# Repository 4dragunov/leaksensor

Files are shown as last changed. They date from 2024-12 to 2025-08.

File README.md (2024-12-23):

# LoRaWAN end-device stack implementation and example projects

      ______                              _
     / _____)             _              | |
    ( (____  _____ ____ _| |_ _____  ____| |__
     \____ \| ___ |    (_   _) ___ |/ ___)  _ \
     _____) ) ____| | | || |_| ____( (___| | | |
    (______/|_____)_|_|_| \__)_____)\____)_| |_|
        (C)2013-2022 Semtech

     ___ _____ _   ___ _  _____ ___  ___  ___ ___
    / __|_   _/_\ / __| |/ / __/ _ \| _ \/ __| __|
    \__ \ | |/ _ \ (__| ' <| _| (_) |   / (__| _|
    |___/ |_/_/ \_\___|_|\_\_| \___/|_|_\\___|___|
    embedded.connectivity.solutions===============

## Introduction

The aim of this project is to show an example of an end-device LoRaWAN stack implementation.

This project has 2 active branches in place.

| Branch | L2 spec | RP spec | Tag/Milestone | Class | Comments |
| --- |:---:|:---:|:---:|:---:|:---|
| | [1.0.4](https://resources.lora-alliance.org/technical-specifications/ts001-1-0-4-lorawan-l2-1-0-4-specification) / [1.1.0](https://resources.lora-alliance.org/technical-specifications/lorawan-specification-v1-1) + [FCntDwn ERRATA](https://resources.lora-alliance.org/technical-specifications/fopts-encryption-usage-of-fcntdwn-errata-on-the-lorawan-l2-1-1-specification) | [2-1.0.3](https://resources.lora-alliance.org/technical-specifications/rp2-1-0-3-lorawan-regional-parameters) | [v4.7.0](https://github.com/Lora-net/LoRaMac-node/releases/tag/v4.7.0) | A/B/C | LoRaWAN L2 1.0.4 - **_Released_** |
| [master](https://github.com/Lora-net/LoRaMac-node/tree/master) | [1.0.4](https://resources.lora-alliance.org/technical-specifications/ts001-1-0-4-lorawan-l2-1-0-4-specification) / [1.1.0](https://resources.lora-alliance.org/technical-specifications/lorawan-specification-v1-1) + [FCntDwn ERRATA](https://resources.lora-alliance.org/technical-specifications/fopts-encryption-usage-of-fcntdwn-errata-on-the-lorawan-l2-1-1-specification) | [2-1.0.3](https://resources.lora-alliance.org/technical-specifications/rp2-1-0-3-lorawan-regional-parameters) | [v4.7.0](https://github.com/Lora-net/LoRaMac-node/milestone/10) | A/B/C |  LoRaWAN L2 1.0.4 / 1.1.0 |
| [v5.0.0-branch](https://github.com/Lora-net/LoRaMac-node/tree/v5.0.0-branch) | [1.0.4](https://resources.lora-alliance.org/technical-specifications/ts001-1-0-4-lorawan-l2-1-0-4-specification) / [1.1.0](https://resources.lora-alliance.org/technical-specifications/lorawan-specification-v1-1) + [FCntDwn ERRATA](https://resources.lora-alliance.org/technical-specifications/fopts-encryption-usage-of-fcntdwn-errata-on-the-lorawan-l2-1-1-specification) | [2-1.0.3](https://resources.lora-alliance.org/technical-specifications/rp2-1-0-3-lorawan-regional-parameters) | [M 5.0.0](https://github.com/Lora-net/LoRaMac-node/milestone/11) | A/B/C |  LoRaWAN L2 1.0.4 / 1.1.0 - Adds support for LR-FHSS modulation |

This project fully implements ClassA, ClassB and ClassC end-device classes and it also provides SX1272/73, SX1276/77/78/79, SX1261/2 and LR1110 radio drivers.

For each currently supported platform example applications are provided.

* **LoRaMac/fuota-test-01**: FUOTA test scenario 01 end-device example application. (Based on provided application common packages)

* **LoRaMac/periodic-uplink-lpp**: ClassA/B/C end-device example application. Periodically uplinks a frame using the Cayenne LPP protocol. (Based on provided application common packages)

* **ping-pong**: Point to point RF link example application.

* **rx-sensi**: Example application useful to measure the radio sensitivity level using an RF generator.

* **tx-cw**: Example application to show how to generate an RF Continuous Wave transmission.

**Note**: *Each LoRaWAN application example (LoRaMac/\*) includes an implementation of the LoRa-Alliance; LoRaWAN certification protocol.*

**Note**: *The LoRaWAN stack API documentation can be found at: http://stackforce.github.io/LoRaMac-doc/*

## Supported platforms

This project currently provides support for the below platforms.  
This project can be ported to other platforms using different MCU than the ones currently supported.  
The [Porting Guide](https://stackforce.github.io/LoRaMac-doc/LoRaMac-doc-v4.7.0/_p_o_r_t_i_n_g__g_u_i_d_e.html) document provides guide lines on how to port the project to other platforms.

* NAMote72
  * [NAMote72 platform documentation](doc/NAMote72-platform.md)

* NucleoLxxx - Discovery kit
  * [NucleoLxxx and Discovery kit platforms documentation](doc/NucleoLxxx-platform.md)

* SKiM880B, SKiM980A, SKiM881AXL
  * [SKiM88xx platforms documentation](doc/SKiM88xx-platform.md)

* SAMR34
  * [SAMR34 platform documentation](doc/SAMR34-platform.md)

## Getting Started

### Prerequisites

Please follow instructions provided by [Development environment](doc/development-environment.md) document.

### Cloning the repository

Clone the repository from GitHub

```bash
$ git clone https://github.com/lora-net/loramac-node.git loramac-node
```

LoRaMac-node project contains Git submodules that must be initialized

```bash
$ cd loramac-node
$ git submodule update --init
```

### Secure-element commissioning

This project currently supports 3 different secure-elements `soft-se`, `lr1110-se`
and `atecc608a-tnglora-se` implementations.

In order to personalize the MCU binary file with LoRaWAN EUIs or/and AES128 keys
one must follow the instructions provided by [soft-se](####soft-se),
 [lr1110-se](####lr1110-se) and [atecc608a-tnglora-se](####atecc608a-tnglora-se) chapters

#### soft-se

*soft-se* is a pure software emulation of a secure-element. It means that everything is located on the host MCU memories. The `DevEUI`, `JoinEUI` and `AES128 keys` may be stored on a non-volatile memory through dedicated APIs.

In order to update the end-device identity (`DevEUI`, `JoinEUI` and `AES128 keys`) one must update the `se-identity.h` file located under `./src/peripherals/soft-se/` directory.  

**Note:** In previous versions of this project this was done inside `Commissioning.h` files located under each provided example directory.

#### lr1110-se

*lr1110-se* abstraction implementation handles all the required exchanges with the LR1110 radio crypto-engine.

All LR1110 radio chips are pre-provisioned out of factory in order to be used with [LoRa Cloud Device Join Service](https://www.loracloud.com/documentation/join_service).  

In case other Join Servers are to be used the `DevEUI`, `Pin`, `JoinEUI` and `AES128 keys` can be updated by following the instructions provided on chapter "13. LR1110 Provisioning" of the [LR1110 User Manual](https://semtech.my.salesforce.com/sfc/p/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).

When the compile option `SECURE_ELEMENT_PRE_PROVISIONED` is set to `ON` the *lr1110-se* will use the factory provisioned data (`DevEUI`, `JoinEUI` and `AES128 keys`).  
When the compile option `SECURE_ELEMENT_PRE_PROVISIONED` is set to `OFF` the *lr1110-se* has to be provisioned by following one of the methods described on chapter "13. LR1110 Provisioning" of the [LR1110 User Manual](https://semtech.my.salesforce.com/sfc/p/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).
The `DevEUI`, `Pin` and `JoinEUI` can be changed by editing the `se-identity.h` file located in `./src/peripherals/lr1110-se/` directory.

#### atecc608a-tnglora-se

The *atecc608a-tnglora-se* abstraction implementation handles all the required exchanges with the ATECC608A-TNGLORA and ATECC608B-TNGLORA secure-elements.

This secure-element is always pre-provisioned and its contents can't be changed.

### Building Process

#### Command line

**periodic-uplink-lpp** example for NucleoL476 platform with LR1110MB1DIS MBED shield and using LR1110 pre-provisioned secure-element

```bash
$ mkdir build
$ cd build
$ cmake -DCMAKE_BUILD_TYPE=Release \
        -DTOOLCHAIN_PREFIX="<replace by toolchain path>" \
        -DCMAKE_TOOLCHAIN_FILE="../cmake/toolchain-arm-none-eabi.cmake" \
        -DAPPLICATION="LoRaMac" \
        -DSUB_PROJECT="periodic-uplink-lpp" \
        -DCLASSB_ENABLED="ON" \
        -DACTIVE_REGION="LORAMAC_REGION_EU868" \
        -DREGION_EU868="ON" \
        -DREGION_US915="OFF" \
        -DREGION_CN779="OFF" \
        -DREGION_EU433="OFF" \
        -DREGION_AU915="OFF" \
        -DREGION_AS923="OFF" \
        -DREGION_CN470="OFF" \
        -DREGION_KR920="OFF" \
        -DREGION_IN865="OFF" \
        -DREGION_RU864="OFF" \
        -DBOARD="NucleoL476" \
        -DMBED_RADIO_SHIELD="LR1110MB1XXS" \
        -DSECURE_ELEMENT="LR1110_SE" \
        -DSECURE_ELEMENT_PRE_PROVISIONED="ON" \
        -DUSE_RADIO_DEBUG="ON" ..
$ make
```

**ping-pong** example using LoRa modulation for NucleoL476 platform with LR1110MB1DIS MBED shield

```bash
$ mkdir build
$ cd build
$ cmake -DCMAKE_BUILD_TYPE=Release \
        -DTOOLCHAIN_PREFIX="<replace by toolchain path>" \
        -DCMAKE_TOOLCHAIN_FILE="../cmake/toolchain-arm-none-eabi.cmake" \
        -DAPPLICATION="ping-pong" \
        -DMODULATION:"LORA" \
        -DREGION_EU868="ON" \
        -DREGION_US915="OFF" \
        -DREGION_CN779="OFF" \
        -DREGION_EU433="OFF" \
        -DREGION_AU915="OFF" \
        -DREGION_AS923="OFF" \
        -DREGION_CN470="OFF" \
        -DREGION_KR920="OFF" \
        -DREGION_IN865="OFF" \
        -DREGION_RU864="OFF" \
        -DBOARD="NucleoL476" \
        -DMBED_RADIO_SHIELD="LR1110MB1XXS" \
        -DUSE_RADIO_DEBUG="ON" ..
$ make
```

#### VSCode

**periodic-uplink-lpp** example for NucleoL476 platform with LR1110MB1DIS MBED shield and using LR1110 pre-provisioned secure-element

* Please edit .vscode/settings.json file

<details>
  <summary>Click to expand!</summary>
<p>

```json
// Place your settings in this file to overwrite default and user settings.
{
    "cmake.configureSettings": {

        // In case your GNU ARM-Toolchain is not installed under the default
        // path:
        //     Windows : No default path. Specify the path where the
        //               toolchain is installed. i.e:
        //               "C:/PROGRA~2/GNUTOO~1/92019-~1".
        //     Linux   : /usr
        //     OSX     : /usr/local
        // It is required to uncomment and to fill the following line.
        "TOOLCHAIN_PREFIX":"/path/to/toolchain",

        // In case your OpenOCD is not installed under the default path:
        //     Windows : C:/openocd/bin/openocd.exe
        //     Linux   : /usr/bin/openocd
        //     OSX     : /usr/local/bin/openocd
        // Please uncomment the following line and fill it accordingly.
        //"OPENOCD_BIN":"C:/openocd/bin/openocd.exe",

        // Specifies the path to the CMAKE toolchain file.
        "CMAKE_TOOLCHAIN_FILE":"cmake/toolchain-arm-none-eabi.cmake",

        // Determines the application. You can choose between:
        // LoRaMac (Default), ping-pong, rx-sensi, tx-cw.
        "APPLICATION":"LoRaMac",

        // Select LoRaMac sub project. You can choose between:
        // periodic-uplink-lpp, fuota-test-01.
        "SUB_PROJECT":"periodic-uplink-lpp",

        // Switch for Class B support of LoRaMac:
        "CLASSB_ENABLED":"ON",

        // Select the active region for which the stack will be initialized.
        // You can choose between:
        // LORAMAC_REGION_EU868, LORAMAC_REGION_US915, ..
        "ACTIVE_REGION":"LORAMAC_REGION_EU868",

        // Select the type of modulation, applicable to the ping-pong or
        // rx-sensi applications. You can choose between:
        // LORA or FSK
        "MODULATION":"LORA",

        // Target board, the following boards are supported:
        // NAMote72, NucleoL073 (Default), NucleoL152, NucleoL476, SAMR34, SKiM880B, SKiM980A, SKiM881AXL, B-L072Z-LRWAN1.
        "BOARD":"NucleoL476",

        // MBED Radio shield selection. (Applies only to Nucleo platforms)
        // The following shields are supported:
        // SX1272MB2DAS, SX1276MB1LAS, SX1276MB1MAS, SX1261MBXBAS(Default), SX1262MBXCAS, SX1262MBXDAS, LR1110MB1XXS.
        "MBED_RADIO_SHIELD":"LR1110MB1XXS",

        // Secure element type selection the following are supported
        // SOFT_SE(Default), LR1110_SE, ATECC608A_TNGLORA_SE
        "SECURE_ELEMENT":"LR1110_SE",

        // Secure element is pre-provisioned
        "SECURE_ELEMENT_PRE_PROVISIONED":"ON",

        // Region support activation, Select the ones you want to support.
        // By default only REGION_EU868 support is enabled.
        "REGION_EU868":"ON",
        "REGION_US915":"OFF",
        "REGION_CN779":"OFF",
        "REGION_EU433":"OFF",
        "REGION_AU915":"OFF",
        "REGION_AS923":"OFF",
        "REGION_CN470":"OFF",
        "REGION_KR920":"OFF",
        "REGION_IN865":"OFF",
        "REGION_RU864":"OFF",
        "USE_RADIO_DEBUG":"ON"
    }
}
```

</p>
</details>

* Click on "CMake: Debug: Ready" and select build type Debug or Release.  
cmake configure
* Wait for configuration process to finish
* Click on "Build" to build the project.  
cmake build
* Wait for build process to finish
* Binary files will be available under `./build/src/apps/LoRaMac/`
  * LoRaMac-periodic-uplink-lpp     - elf format
  * LoRaMac-periodic-uplink-lpp.bin - binary format
  * LoRaMac-periodic-uplink-lpp.hex - hex format

**ping-pong** example using LoRa modulation for NucleoL476 platform with LR1110MB1DIS MBED shield

* Please edit .vscode/settings.json file

<details>
  <summary>Click to expand!</summary>
<p>

```json
// Place your settings in this file to overwrite default and user settings.
{
    "cmake.configureSettings": {

        // In case your GNU ARM-Toolchain is not installed under the default
        // path:
        //     Windows : No default path. Specify the path where the
        //               toolchain is installed. i.e:
        //               "C:/PROGRA~2/GNUTOO~1/92019-~1".
        //     Linux   : /usr
        //     OSX     : /usr/local
        // It is required to uncomment and to fill the following line.
        "TOOLCHAIN_PREFIX":"/path/to/toolchain",

        // In case your OpenOCD is not installed under the default path:
        //     Windows : C:/openocd/bin/openocd.exe
        //     Linux   : /usr/bin/openocd
        //     OSX     : /usr/local/bin/openocd
        // Please uncomment the following line and fill it accordingly.
        //"OPENOCD_BIN":"C:/openocd/bin/openocd.exe",

        // Specifies the path to the CMAKE toolchain file.
        "CMAKE_TOOLCHAIN_FILE":"cmake/toolchain-arm-none-eabi.cmake",

        // Determines the application. You can choose between:
        // LoRaMac (Default), ping-pong, rx-sensi, tx-cw.
        "APPLICATION":"ping-pong",

        // Select LoRaMac sub project. You can choose between:
        // periodic-uplink-lpp, fuota-test-01.
        "SUB_PROJECT":"periodic-uplink-lpp",

        // Switch for Class B support of LoRaMac:
        "CLASSB_ENABLED":"ON",

        // Select the active region for which the stack will be initialized.
        // You can choose between:
        // LORAMAC_REGION_EU868, LORAMAC_REGION_US915, ..
        "ACTIVE_REGION":"LORAMAC_REGION_EU868",

        // Select the type of modulation, applicable to the ping-pong or
        // rx-sensi applications. You can choose between:
        // LORA or FSK
        "MODULATION":"LORA",

        // Target board, the following boards are supported:
        // NAMote72, NucleoL073 (Default), NucleoL152, NucleoL476, SAMR34, SKiM880B, SKiM980A, SKiM881AXL, B-L072Z-LRWAN1.
        "BOARD":"NucleoL476",

        // MBED Radio shield selection. (Applies only to Nucleo platforms)
        // The following shields are supported:
        // SX1272MB2DAS, SX1276MB1LAS, SX1276MB1MAS, SX1261MBXBAS(Default), SX1262MBXCAS, SX1262MBXDAS, LR1110MB1XXS.
        "MBED_RADIO_SHIELD":"SX1261MBXBAS",

        // Secure element type selection the following are supported
        // SOFT_SE(Default), LR1110_SE, ATECC608A_TNGLORA_SE
        "SECURE_ELEMENT":"SOFT_SE",

        // Secure element is pre-provisioned
        "SECURE_ELEMENT_PRE_PROVISIONED":"ON",

        // Region support activation, Select the ones you want to support.
        // By default only REGION_EU868 support is enabled.
        "REGION_EU868":"ON",
        "REGION_US915":"OFF",
        "REGION_CN779":"OFF",
        "REGION_EU433":"OFF",
        "REGION_AU915":"OFF",
        "REGION_AS923":"OFF",
        "REGION_CN470":"OFF",
        "REGION_KR920":"OFF",
        "REGION_IN865":"OFF",
        "REGION_RU864":"OFF",
        "USE_RADIO_DEBUG":"ON"
    }
}
```

</p>
</details>

* Click on "CMake: Debug: Ready" and select build type Debug or Release.  
cmake configure
* Wait for configuration process to finish
* Click on "Build" to build the project.  
cmake build
* Wait for build process to finish
* Binary files will be available under `./build/src/apps/ping-pong/`
  * ping-pong     - elf format
  * ping-pong.bin - binary format
  * ping-pong.hex - hex format

### Serial console NVM management

The `periodic-uplink-lpp` and `fuota-test-01` examples allow to reset the NVM storage through the serial interface.

In order to reset the NVM contents one must hit `ESC` + `N` keyboard keys on a serial terminal.

The serial terminal will show the following after `ESC` + `N` keyboard keys are hit. After reseting the end-device the clean NVM will be used.

```text
ESC + N

NVM factory reset succeed

PLEASE RESET THE END-DEVICE
```

## Acknowledgments

* The mbed (https://mbed.org/) project was used at the beginning as source of
inspiration.
* This program uses the AES algorithm implementation (http://www.gladman.me.uk/) by Brian Gladman.
* This program uses the CMAC algorithm implementation
(http://www.cse.chalmers.se/research/group/dcs/masters/contikisec/) by Lander Casado, Philippas Tsigas.
* [The Things Industries](https://www.thethingsindustries.com/) for providing
 Microchip/Atmel SAMR34 platform and ATECC608A-TNGLORA secure-element support.
* Tencent Blade Team for security breach findings and solving propositions.

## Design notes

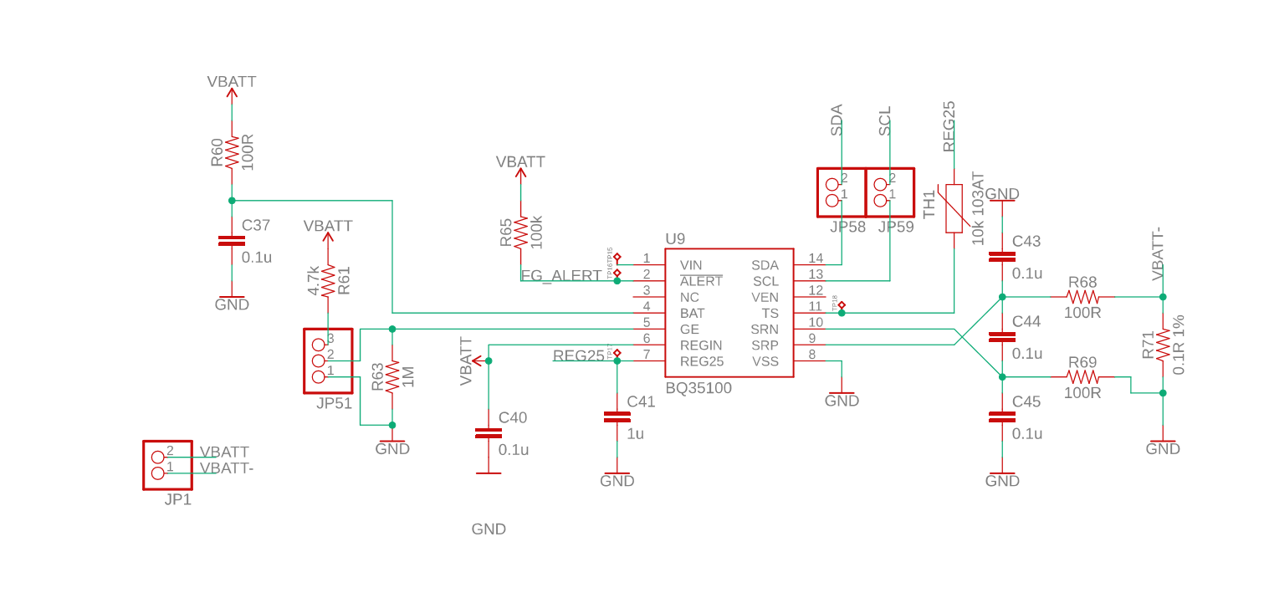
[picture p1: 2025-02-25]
doc/board/water-leak/3362.schematic.png

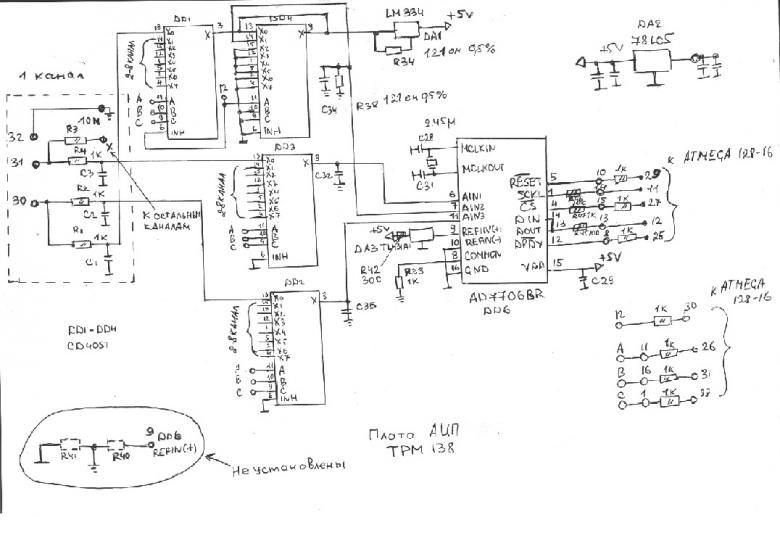
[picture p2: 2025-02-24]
doc/board/trm138_dac_-_kopiya.jpg

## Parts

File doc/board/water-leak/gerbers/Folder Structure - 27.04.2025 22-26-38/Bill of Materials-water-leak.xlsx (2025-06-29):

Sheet: Sheet1
 | Bill of Materials
 |  |  |  |  |  |  | 2175 Salk Avenue
 | Project Title: | Bill of Materials for Project [water-leak.PrjPcb] (No PCB Document Selected) |  |  |  |  | Suite 200
 | Project File Name: | water-leak.PrjPcb |  |  |  |  | Carlsbad, CA 92008
 | Assembly Variant: | None |  |  |  |  | USA
Part Number | Description | Designator | Manufacture | Manufacture Part Number | Supplier | Supplier Part Number | Supplier Unit Price | Quantity
AMAN903012ST05 | RF Ant 434/868/915MHz | A1 |  |  |  |  |  | 1
ML-621SDN | No Description Available | B1 |  |  |  |  |  | 1
TMK107BBJ475KA-T | SMT Capacitor | C1, C7, C11 |  |  | DigiKey | 587-4321-1-ND |  | 3
CL10B104KO8NNNC, VJ0603Y104MXQCW1BC | SMT Capacitor | C2, C3, C4, C5, C6, C8, C12, C13, C38_SI0, C38_SI1, C39_SI0, C39_SI1, C40_SI0, C40_SI1, C41_SI0, C41_SI1, C42_SI0, C42_SI1, C52, C53, C54, C55, C58, C81 |  |  | DigiKey | 1276-1005-1-ND, 720-VJ0603Y104MXQCW1BCCT-ND |  | 24
QSCP251Q5R1C1GV001T | SMT Capacitor | C9, C10, C23 |  |  | DigiKey | 712-QSCP251Q5R1C1GV001TCT-ND |  | 3
EEE-FK1V471SP | Capacitor Polarised | C14 |  |  |  |  |  | 1
VJ0603D100JXPAJ, VJ0603D100FXPAJ | SMT Capacitor | C15, C27, C80 |  |  | DigiKey | 720-1299-1-ND, 720-VJ0603D100FXPAJCT-ND |  | 3
C0603X152J4HAC7867 | SMT Capacitor | C16_SI0, C16_SI1, C26, C31, C35, C62, C63, C64, C65 |  |  | DigiKey | 399-C0603X152J4HAC7867CT-ND |  | 9
VJ0603Y102JXACW1BC | SMT Capacitor | C17, C28 |  |  | DigiKey | 720-VJ0603Y102JXACW1BCCT-ND |  | 2
UMK107B7474KA-TR | SMT Capacitor | C18 |  |  | DigiKey | 587-3170-1-ND |  | 1
VJ0603Y473KXJCW1BC | SMT Capacitor | C19 |  |  | DigiKey | 720-VJ0603Y473KXJCW1BCCT-ND |  | 1
VJ0603D680JXAQJHT, VJ0603D680JXCAJ | SMT Capacitor | C20, C22 |  |  | DigiKey | 720-VJ0603D680JXAQJHTCT-ND, 720-VJ0603D680JXCAJCT-ND |  | 2
VJ0603D2R0BXPAJ | SMT Capacitor | C21 |  |  | DigiKey | 720-1310-1-ND |  | 1
VJ0603D0R7VXPAJ | SMT Capacitor | C24 |  |  | DigiKey | 720-VJ0603D0R7VXPAJCT-ND |  | 1
VJ0603D0R7VXPAJ | SMT Capacitor | C25 |  |  | DigiKey | 720-VJ0603D0R7VXPAJCT-ND |  | 1
VJ0603D3R0BXPAJ | SMT Capacitor | C29 |  |  | DigiKey | 720-1317-1-ND |  | 1
C4532X5R0J107M280KA | SMT Capacitor | C30, C69, C70 |  |  | DigiKey | 445-1413-1-ND |  | 3
VJ0603D1R0BXCQJHT | SMT Capacitor | C32 |  |  | DigiKey | 720-VJ0603D1R0BXCQJHTCT-ND |  | 1
VJ0603D3R3CXBAJ | SMT Capacitor | C33, C34 |  |  | DigiKey | 720-VJ0603D3R3CXBAJCT-ND |  | 2
VJ0603D4R7CXPAJ | SMT Capacitor | C36 |  |  | DigiKey | 720-1321-1-ND |  | 1
VJ0603D330FXPAJ | SMT Capacitor | C37, C57, C79 |  |  | DigiKey | 720-VJ0603D330FXPAJCT-ND |  | 3
VJ0603Y105KXJPW1BC, VJ0603Y105KXJCW1BC | SMT Capacitor | C47, C48, C50, C56 |  |  | DigiKey | 720-VJ0603Y105KXJPW1BCCT-ND, 720-1852-1-ND |  | 4
VJ0603Y332KXAAC | SMT Capacitor | C49 |  |  | DigiKey | 720-1366-1-ND |  | 1
6SVPE150M | SMT Polarised Capacitor | C51 |  |  | DigiKey | P16614CT-ND |  | 1
VJ0603D220JXBQJHT | SMT Capacitor | C59 |  |  | DigiKey | 720-VJ0603D220JXBQJHTCT-ND |  | 1
ZRB186R60J226ME11L | SMT Capacitor | C60, C61, C66, C67 |  |  | DigiKey | 490-13254-1-ND |  | 4
1210DD105KAT2A | SMT Capacitor | C71 |  |  | DigiKey | 478-12269-1-ND |  | 1
GCM1885C2A5R0CA16D | DNP, SMT Capacitor | C82, C83 |  |  | DigiKey | 490-GCM1885C2A5R0CA16DCT-ND |  | 2
CC0805MRX7R9BB104 | SMT Capacitor | C84, C86 |  |  | DigiKey | 311-4351-1-ND |  | 2
VJ0805G106KXYTW1BC | SMT Capacitor | C85 |  |  | DigiKey | 720-VJ0805G106KXYTW1BCCT-ND |  | 1
VJ0805G106KXYTW1BC | SMT Capacitor | C87 |  |  | DigiKey | 720-VJ0805G106KXYTW1BCCT-ND |  | 1
PESD3V3L2BT | TVS Diode (Uni-directional) | D3_WS1, D3_WS2, D3_WS3, D3_WS4, D3_WS5, D3_WS6, D3_WS7, D3_WS8, D3_WS9, D3_WS10, D3_WS11, D3_WS12, D3_WS13, D3_WS14, D3_WS15, D3_WS16, D3_WS17, D3_WS18, D3_WS19, D3_WS20 |  |  |  |  |  | 20
10MQ040NTR | DIODE SCHOTTKY 40V 1A SMA | D4 |  |  | DigiKey | 1655-2293-1-ND |  | 1
1KSMB33A | TVS DIODE 28.2VWM 45.7VC DO214AA | D5 |  |  | DigiKey | F11450CT-ND |  | 1
ACDBA2100-HF | DIODE SCHOTTKY 100V 2A DO214AC | D6, D7 |  |  | DigiKey | 641-1873-1-ND |  | 2
1N6263W-7-F | DIODE SCHOTTKY 60V 15MA SOD123 | D8, D9, D16, D17 |  |  | DigiKey | 1N6263W-FDICT-ND |  | 4
SM712 | TVS Diode (Bi-directional) | D10, D11, D12, D13 |  |  |  |  |  | 4
PESD3V3L1BA,115 | TVS DIODE 3.3VWM 26VC SOD323 | D14 |  |  | DigiKey | 1727-3825-1-ND |  | 1
SF-1206F050-2 | FUSE BOARD MNT 500MA 63VDC 1206 | F1 |  |  | DigiKey | SF-1206F050-2CT-ND |  | 1
3413.0113.22 | FUSE BOARD MNT 500MA 125VAC/VDC | F2 |  |  | DigiKey | 486-1675-1-ND |  | 1
TRF250-080U | Fuse | F3, F4, F5, F6 |  |  |  |  |  | 4
AD8541ARTZ-REEL7 | IC OPAMP GP 1 CIRCUIT SOT23-5 | IC1, IC2, IC3 |  |  | DigiKey | AD8541ARTZ-REEL7CT-ND |  | 3
SN74LVC1G74DCUR | Integrated Circuit | IC5 |  |  |  |  |  | 1
SN74LVC2G17DBVR | Integrated Circuit | IC6 |  |  |  |  |  | 1
LM2594M-3.3_NOPB | Integrated Circuit | IC7 |  |  |  |  |  | 1
NSIP83086V-DSWR | Integrated Circuit | IC8 |  |  |  |  |  | 1
IRLML6302TRPBF | MOSFET P-CH 20V 780MA SOT23 | IC9 |  |  | DigiKey | IRLML6302PBFCT-ND |  | 1
NC7WZ07P6X | Integrated Circuit | IC10 |  |  |  |  |  | 1
DS9503P+ | Integrated Circuit | IC11 |  |  |  |  |  | 1
TSP63900 | Integrated Circuit | IC13 |  |  |  |  |  | 1
74AHC1G14SE-7 | IC INVERTER SCHMITT 1CH SOT353 | IC14 |  |  | DigiKey | 74AHC1G14SE-7DICT-ND |  | 1
ADP160AUJZ-3.3-R7 | Integrated Circuit | IC15 |  |  |  |  |  | 1
LM334M_NOPB | Integrated Circuit | IC16 |  |  |  |  |  | 1
FDN306P | MOSFET P-CH 12V 2.6A SSOT3 | IC17 |  |  | DigiKey | FDN306PCT-ND |  | 1
SKY13446-374LF | IC RF SWITCH SPDT 6GHZ 6MLPD | IC18 |  |  | DigiKey | 863-1601-1-ND |  | 1
B2B-PH-K-S(LF)(SN) | CONN HEADER VERT 2POS 2MM | J2 |  |  | DigiKey | 455-1704-ND |  | 1
282834-2 | TERM BLK 2P SIDE ENT 2.54MM PCB | J3, J? |  |  | DigiKey | A98333-ND |  | 2
1909763-1 | CONN UMCC JACK STR 50OHM SMD | J4 |  |  | DigiKey | A118077CT-ND |  | 1
282834-5 | TERM BLK 5P SIDE ENT 2.54MM PCB | J5 |  |  | DigiKey | A98336-ND |  | 1
3221-10-0300-00 | CONN HEADER SMD 10POS 1.27MM | J6 |  |  | DigiKey | 1175-1735-ND |  | 1
MCD-00047 | SMD Chip ferrite bead, 600R@100MHz +/-25%, 350mA, 500mohm DC, 0603, T=0.8mm | L1 |  |  |  |  |  | 1
MCD-01433 | MLZ2012 Multilayer Shielded Inductor 15µH, ±5% | L2 |  |  |  |  |  | 1
MCD-01330 |  | L3, L4, L5, L6, L7, L8 |  |  |  |  |  | 6
DFE252012F-2R2M=P2 | Inductor | L9 |  |  |  |  |  | 1
7447715470 | FIXED IND 47UH 1.95A 125MOHM SMD | L10 |  |  | DigiKey | 732-2197-1-ND |  | 1
744761039C, 744917039 | FIXED IND 3.9NH 700MA 70 MOHM, FIXED IND 3.9NH 1.6A 39 MOHM SMD | L12, L13 |  |  | DigiKey | 732-1747-1-ND, 732-11258-1-ND |  | 2
LQW18AN27NG8ZD | FIXED IND 27NH 1.2A 0.098OHM SMD | L14 |  |  | DigiKey | 490-15666-1-ND |  | 1
S0981-46R | Mechanical Part | MP1, MP2, MP3, MP4 |  |  |  |  |  | 4
MCD-00220 | Resistor,10K,0603,1%,1/10W | R1 |  |  |  |  |  | 1
AC0603FR-7W100RL | RES 100 OHM 1% 1/5W 0603 | R2, R3 |  |  | DigiKey | 13-AC0603FR-7W100RLCT-ND |  | 2
AA0603FR-071KL | RES SMD 1K OHM 1% 1/10W 0603 | R4_SI0, R4_SI1, R9, R10, R11, R12_SI0, R12_SI1, R14_SI0, R14_SI1, R15, R16_SI0, R16_SI1, R17_SI0, R17_SI1, R18_SI0, R18_SI1, R19_WS1, R19_WS2, R19_WS3, R19_WS4, R19_WS5, R19_WS6, R19_WS7, R19_WS8, R19_WS9, R19_WS10, R19_WS11, R19_WS12, R19_WS13, R19_WS14, R19_WS15, R19_WS16, R19_WS17, R19_WS18, R19_WS19, R19_WS20, R20_WS1, R20_WS2, R20_WS3, R20_WS4, R20_WS5, R20_WS6, R20_WS7, R20_WS8, R20_WS9, R20_WS10, R20_WS11, R20_WS12, R20_WS13, R20_WS14, R20_WS15, R20_WS16, R20_WS17, R20_WS18, R20_WS19, R20_WS20, R21_WS1, R21_WS2, R21_WS3, R21_WS4, R21_WS5, R21_WS6, R21_WS7, R21_WS8, R21_WS9, R21_WS10, R21_WS11, R21_WS12, R21_WS13, R21_WS14, R21_WS15, R21_WS16, R21_WS17, R21_WS18, R21_WS19, R21_WS20, R22_WS1, R22_WS2, R22_WS3, R22_WS4, R22_WS5, R22_WS6, R22_WS7, R22_WS8, R22_WS9, R22_WS10, R22_WS11, R22_WS12, R22_WS13, R22_WS14, R22_WS15, R22_WS16, R22_WS17, R22_WS18, R22_WS19, R22_WS20, R53, R57 |  |  | DigiKey | 13-AA0603FR-071KLCT-ND |  | 98
YJP1608-R001 | RES SMD 0 OHM JUMPER 0603 | R5, R6, R60, R63 |  |  | DigiKey | 408-1515-1-ND |  | 4
AC0603FR-7W220RL | RES 220 OHM 1% 1/5W 0603 | R7, R61 |  |  | DigiKey | 13-AC0603FR-7W220RLCT-ND |  | 2
AC0603FR-7W1ML | RES 1 MOHM 1% 1/5W 0603 | R8, R32, R62 |  |  | DigiKey | 13-AC0603FR-7W1MLCT-ND |  | 3
AA0603FR-07100KL | RES SMD 100K OHM 1% 1/10W 0603 | R13_SI0, R13_SI1, R70 |  |  | DigiKey | 13-AA0603FR-07100KLCT-ND |  | 3
CRCW0603102KFKEA | RES SMD 102K OHM 1% 1/10W 0603 | R23, R25 |  |  | DigiKey | 541-102KHCT-ND |  | 2
TFPT0603L1001FV | THERMISTOR PTC 1K OHM 1% 0603 | R24 |  |  | DigiKey | 541-1166-1-ND |  | 1
CRCW0603100RFKTA, ERJ-U03J101V | RES SMD 100 OHM 1% 1/10W 0603, RES 100 OHM 5% 1/10W 0603 SMD | R26, R28, R30 |  |  | DigiKey | 541-2976-1-ND, 10-ERJ-U03J101VCT-ND |  | 3
ERJ-3GEYJ472V | RES SMD 4.7K OHM 5% 1/10W 0603 | R27 |  |  | DigiKey | P4.7KGCT-ND |  | 1
KDV08DR100ET | RES 0.1 OHM 0.5% 1/4W 0805 | R29 |  |  | DigiKey | 273-KDV08DR100ETCT-ND |  | 1
AC0603FR-7W20KL | RES 20K OHM 1% 1/5W 0603 | R31 |  |  | DigiKey | 13-AC0603FR-7W20KLCT-ND |  | 1
AC0603FR-0736K5L | RES SMD 36.5K OHM 1% 1/10W 0603 | R33 |  |  | DigiKey | 13-AC0603FR-0736K5LCT-ND |  | 1
AC0603JR-0710KL, AR0603JR-0710KL, AC0603JR-1310KL | RES SMD 10K OHM 5% 1/10W 0603, RES 10K OHM 5% 1/10W 0603 | R34, R35, R36, R37, R38, R40, R41, R46, R49, R58, R59 |  |  | DigiKey | 311-10KLECT-ND, 13-AR0603JR-0710KLCT-ND, 13-AC0603JR-1310KLCT-ND |  | 11
AC0603JR-075K6L | RES SMD 5.6K OHM 5% 1/10W 0603 | R39 |  |  | DigiKey | YAG3683CT-ND |  | 1
AF0603JR-074K7L | RES SMD 4.7K OHM 5% 1/10W 0603 | R42 |  |  | DigiKey | 13-AF0603JR-074K7LCT-ND |  | 1
RT0805FRE0710RL | RES SMD 10 OHM 1% 1/8W 0805 | R43, R44, R51, R55 |  |  | DigiKey | YAG5974CT-ND |  | 4
CR0603-JW-221ELF | RES SMD 220 OHM 5% 1/10W 0603 | R45 |  |  | DigiKey | 118-CR0603-JW-221ELFCT-ND |  | 1
CRGH0805J10K | RES SMD 10K OHM 5% 1/3W 0805 | R47, R48, R54 |  |  | DigiKey | A126429CT-ND |  | 3
RK73H2ATTD54R9F | RES 54.9 OHM 1% 1/4W 0805 | R50 |  |  | DigiKey | 2019-RK73H2ATTD54R9FCT-ND |  | 1
CRCW0805120RFKEAHP | RES SMD 120 OHM 1% 1/2W 0805 | R52 |  |  | DigiKey | 541-120TCT-ND |  | 1
TNPW06033K20BEEN | RES 3.2K OHM 0.1% 1/10W 0603 | R56 |  |  | DigiKey | 541-TNPW06033K20BEENCT-ND |  | 1
RF-BOM |  | RF BoM |  |  |  |  |  | 1
RF-Shield | RF Shield Frame + Cover without apertures | S1 |  |  |  |  |  | 1
TMUX1072DGSR | Switch | S2_SI0, S2_SI1 |  |  |  |  |  | 2
SB_0Ohm | Solder Bridge 0R [0402] (Populated with 0 Ohm) | SB1, SB2, SB3, SB4, SB6, SB8, SB11, SB12, SB17, SB18, SB19 |  |  |  |  |  | 11
SB_Open | Solder Bridge Open [0402] (Unpopulated) | SB5, SB7, SB13, SB20 |  |  |  |  |  | 4
SB_3Pads | Solder Bridge | SB9, SB10, SB15 |  |  |  |  |  | 3
218-2LPSTR | SWITCH SLIDE DIP SPST 25MA 24V | SW1, SW2 |  |  | DigiKey | CT3108CT-ND |  | 2
MUX-74HC4067 | MUX-74HC4067 | U1_SI0, U1_SI1, U5_SI0, U5_SI1, U6_SI0, U6_SI1, U9_SI0, U9_SI1 |  |  |  |  |  | 8
STM32WLxx_QFN48 | HQDC : Verified April, 25 2019 | U4 |  |  |  |  |  | 1
BQ35100PW | No Description Available | U10 |  |  |  |  |  | 1
1708110_2 | 1 row of Connector | WS1, WS2, WS3, WS4, WS5, WS6, WS7, WS8, WS9, WS10, WS11, WS12, WS13, WS14, WS15, WS16, WS17, WS18, WS19, WS20 |  |  |  |  |  | 20
1XXD32000MBA | TXCO 32MHz ±1.5ppm | Y1 |  |  |  |  |  | 1
ABS07-32.768KHZ-7-1-T | CRYSTAL 32.7680KHZ 7PF SMD | Y2 |  |  | DigiKey | 535-13478-1-ND |  | 1
 |  |  |  |  |  |  | $0.00 | 364
Approved |  | Notes

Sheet: Sheet2
Part Number | Quantity
DesignItemId | Quantity
AMAN903012ST05 | 1
ML-621SDN | 1
TMK107BBJ475KA-T | 3
CL10B104KO8NNNC, VJ0603Y104MXQCW1BC | 24
QSCP251Q5R1C1GV001T | 3
EEE-FK1V471SP | 1
VJ0603D100JXPAJ, VJ0603D100FXPAJ | 3
C0603X152J4HAC7867 | 9
VJ0603Y102JXACW1BC | 2
UMK107B7474KA-TR | 1
VJ0603Y473KXJCW1BC | 1
VJ0603D680JXAQJHT, VJ0603D680JXCAJ | 2
VJ0603D2R0BXPAJ | 1
VJ0603D0R7VXPAJ | 1
VJ0603D0R7VXPAJ | 1
VJ0603D3R0BXPAJ | 1
C4532X5R0J107M280KA | 3
VJ0603D1R0BXCQJHT | 1
VJ0603D3R3CXBAJ | 2
VJ0603D4R7CXPAJ | 1
VJ0603D330FXPAJ | 3
VJ0603Y105KXJPW1BC, VJ0603Y105KXJCW1BC | 4
VJ0603Y332KXAAC | 1
6SVPE150M | 1
VJ0603D220JXBQJHT | 1
ZRB186R60J226ME11L | 4
1210DD105KAT2A | 1
GCM1885C2A5R0CA16D | 2
CC0805MRX7R9BB104 | 2
VJ0805G106KXYTW1BC | 1
VJ0805G106KXYTW1BC | 1
PESD3V3L2BT | 20
10MQ040NTR | 1
1KSMB33A | 1
ACDBA2100-HF | 2
1N6263W-7-F | 4
SM712 | 4
PESD3V3L1BA,115 | 1
SF-1206F050-2 | 1
3413.0113.22 | 1
TRF250-080U | 4
AD8541ARTZ-REEL7 | 3
SN74LVC1G74DCUR | 1
SN74LVC2G17DBVR | 1
LM2594M-3.3_NOPB | 1
NSIP83086V-DSWR | 1
IRLML6302TRPBF | 1
NC7WZ07P6X | 1
DS9503P+ | 1
TSP63900 | 1
74AHC1G14SE-7 | 1
ADP160AUJZ-3.3-R7 | 1
LM334M_NOPB | 1
FDN306P | 1
SKY13446-374LF | 1
B2B-PH-K-S(LF)(SN) | 1
282834-2 | 2
1909763-1 | 1
282834-5 | 1
3221-10-0300-00 | 1
MCD-00047 | 1
MCD-01433 | 1
MCD-01330 | 6
DFE252012F-2R2M=P2 | 1
7447715470 | 1
744761039C, 744917039 | 2
LQW18AN27NG8ZD | 1
S0981-46R | 4
MCD-00220 | 1
AC0603FR-7W100RL | 2
AA0603FR-071KL | 98
YJP1608-R001 | 4
AC0603FR-7W220RL | 2
AC0603FR-7W1ML | 3
AA0603FR-07100KL | 3
CRCW0603102KFKEA | 2
TFPT0603L1001FV | 1
CRCW0603100RFKTA, ERJ-U03J101V | 3
ERJ-3GEYJ472V | 1
KDV08DR100ET | 1
AC0603FR-7W20KL | 1
AC0603FR-0736K5L | 1
AC0603JR-0710KL, AR0603JR-0710KL, AC0603JR-1310KL | 11
AC0603JR-075K6L | 1
AF0603JR-074K7L | 1
RT0805FRE0710RL | 4
CR0603-JW-221ELF | 1
CRGH0805J10K | 3
RK73H2ATTD54R9F | 1
CRCW0805120RFKEAHP | 1
TNPW06033K20BEEN | 1
RF-BOM | 1
RF-Shield | 1
TMUX1072DGSR | 2
SB_0Ohm | 11
SB_Open | 4
SB_3Pads | 3
218-2LPSTR | 2
MUX-74HC4067 | 8
STM32WLxx_QFN48 | 1
BQ35100PW | 1
1708110_2 | 20
1XXD32000MBA | 1
ABS07-32.768KHZ-7-1-T | 1
 | 364
Approved

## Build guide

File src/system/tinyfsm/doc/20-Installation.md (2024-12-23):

Installation
============

TinyFSM is an header-only library, no special installation steps are
needed. Just point your compiler to the "include" directory, and in
your source files:

    #include <tinyfsm.hpp>

Prerequisites
-------------

TinyFSM requires a compiler supporting the C++11 language standard
("-std=c++11" in gcc).

TinyFSM does not depend on RTTI, exceptions or any external library.
If you need to compile without standard libraries (e.g. in conjunction
with `-nostdlib` linker option), add `-DTINYFSM_NOSTDLIB` to the
compiler options: this removes all dependencies on the standard
library by disabling some compile-time type checks.

Building the Elevator Example
-----------------------------

Change to the elevator example directory and compile the sources:

    $ cd examples/elevator
    $ make

Our elevator has call buttons on every floor, sensors reporting the
current position, and an alarm button for emergency. These actors can
be triggered via a simple command interface:

    $ ./elevator
    Motor: stopped
    Motor: stopped
    c=Call, f=FloorSensor, a=Alarm, q=Quit ?

Let's call the elevator to floor 2:

    c=Call, f=FloorSensor, a=Alarm, q=Quit ? c
    Floor ? 2
    Motor: moving up
    c=Call, f=FloorSensor, a=Alarm, q=Quit ?

Now the elevator is moving up, and we need to trigger the floor sensor:

    c=Call, f=FloorSensor, a=Alarm, q=Quit ? f
    Floor ? 1
    Reached floor 1
    c=Call, f=FloorSensor, a=Alarm, q=Quit ? f
    Floor ? 2
    Reached floor 2
    Motor: stopped
    c=Call, f=FloorSensor, a=Alarm, q=Quit ?

Now we simulate a sensor defect:

    c=Call, f=FloorSensor, a=Alarm, q=Quit ? c
    Floor ? 1
    Motor: moving down
    c=Call, f=FloorSensor, a=Alarm, q=Quit ? f
    Floor ? 2
    Floor sensor defect (expected 1, got 2)
    *** calling maintenance ***
    Motor: stopped

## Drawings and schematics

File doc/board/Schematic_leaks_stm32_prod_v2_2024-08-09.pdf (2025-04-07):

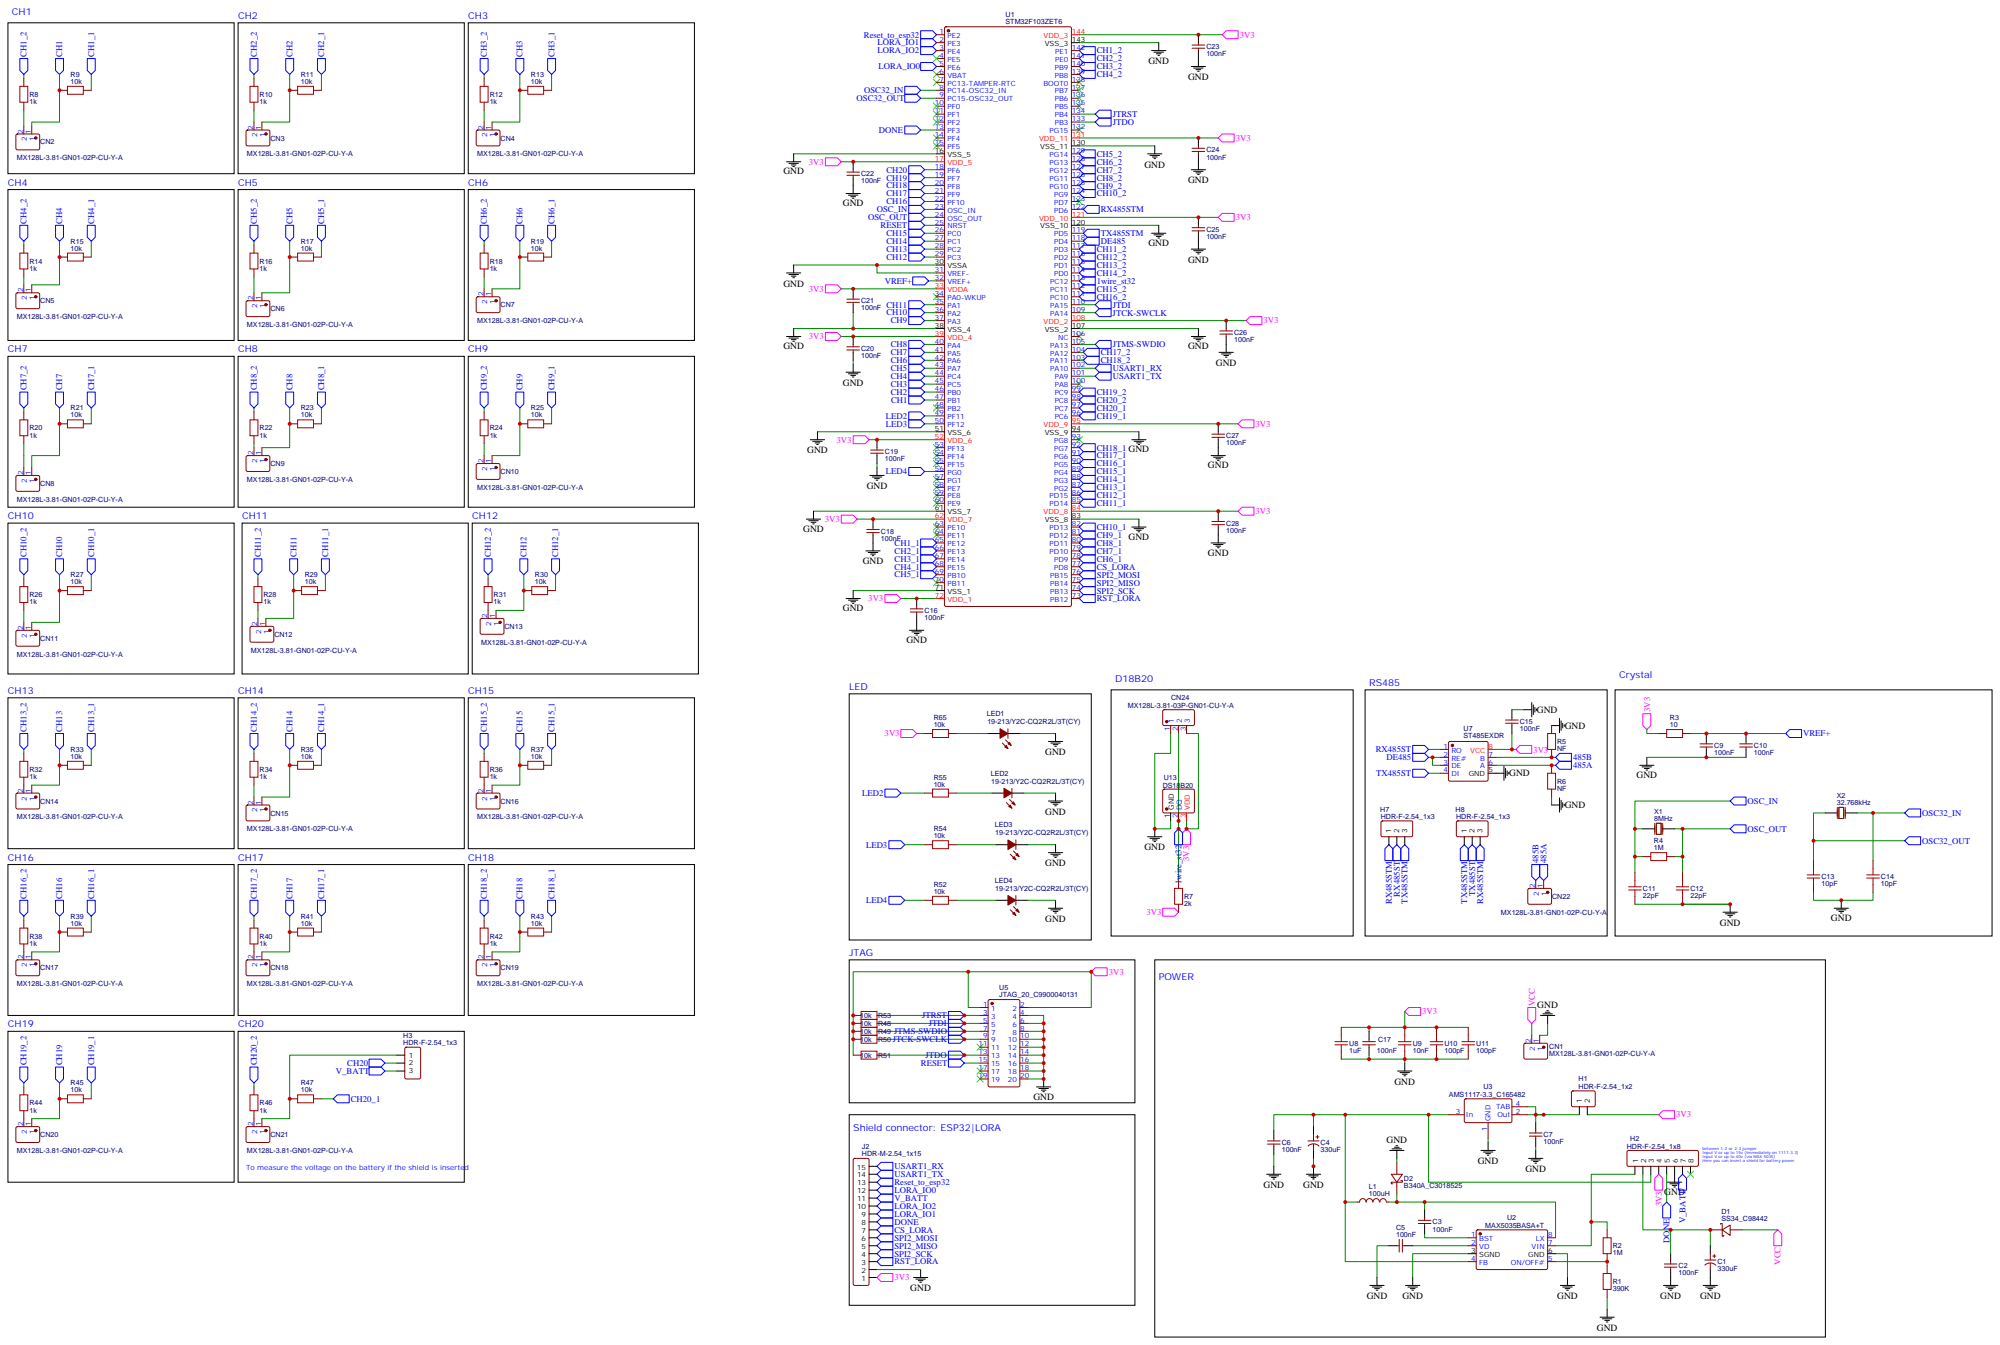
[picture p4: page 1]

between 1-2 or 2-3 jumper
Input V or up to 15v (immediately on 1117-3.3)
Input V or up to 40v (via MAX 5035)
Here you can insert a shield for battery power

To measure the voltage on the battery if the shield is inserted

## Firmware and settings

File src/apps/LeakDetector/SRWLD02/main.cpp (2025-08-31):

/*!
 * \file      main.c
 *
 * \brief     Performs a periodic uplink
 *
 * \copyright Revised BSD License, see section \ref LICENSE.
 *
 * \code
 *                ______                              _
 *               / _____)             _              | |
 *              ( (____  _____ ____ _| |_ _____  ____| |__
 *               \____ \| ___ |    (_   _) ___ |/ ___)  _ \
 *               _____) ) ____| | | || |_| ____( (___| | | |
 *              (______/|_____)_|_|_| \__)_____)\____)_| |_|
 *              (C)2013-2018 Semtech
 *
 * \endcode
 *
 * \author    Miguel Luis ( Semtech )
 */

/*! \file periodic-uplink/NucleoL152/main.c */

#include <stdio.h>
#include <memory>
#include <math.h>
#include <assert.h>
#include <sys/time.h>
#include <time.h>

#include "mav.h"
#include "../firmwareVersion.h"
#include "../../common/githubVersion.h"
#include "utilities.h"
#include "board.h"
#include "gpio.h"
#include "uart.h"
#include "RegionCommon.h"

#include "cli.h"
#include "Commissioning.h"
#include "LmHandler.h"
#include "LmhpCompliance.h"
#include "CayenneLpp.h"
#include "LmHandlerMsgDisplay.h"

#include "board-config.h"
#include "nonvol.h"
#include "utilities.h"
#include "NvmDataMgmt.h"
#include "sensors.h"
#include "modbusnode.h"
#include "onewirenode.h"
#include "loranode.h"
#include "cmsis_os.h"

#define ARRAY_SIZE(x) (sizeof(x)/sizeof(x[0]))

#ifndef ACTIVE_REGION

#warning "No active region defined, LORAMAC_REGION_EU868 will be used as default."

#define ACTIVE_REGION LORAMAC_REGION_EU868

#endif

/*!
 * LoRaWAN default end-device class
 */
#ifndef LORAWAN_DEFAULT_CLASS
#define LORAWAN_DEFAULT_CLASS                      ((BoardGetPowerSource()==EXT_POWER)?CLASS_B:CLASS_A)
#endif

/*!
 * Defines the application data transmission duty cycle. 5s, value in [ms].
 */
#define APP_TX_DUTYCYCLE                            5000

/*!
 * Defines a random delay for application data transmission duty cycle. 1s,
 * value in [ms].
 */
#define APP_TX_DUTYCYCLE_RND                        1000

/*!
 * LoRaWAN Adaptive Data Rate
 *
 * \remark Please note that when ADR is enabled the end-device should be static
 */
#define LORAWAN_ADR_STATE                           LORAMAC_HANDLER_ADR_ON


/*!
 * Default datarate
 *
 * \remark Please note that LORAWAN_DEFAULT_DATARATE is used only when ADR is disabled 
 */
#define LORAWAN_DEFAULT_DATARATE                    DR_0

/*!
 * LoRaWAN confirmed messages
 */
#define LORAWAN_DEFAULT_CONFIRMED_MSG_STATE         LORAMAC_HANDLER_UNCONFIRMED_MSG

/*!
 * User application data buffer size
 */
#define LORAWAN_APP_DATA_BUFFER_MAX_SIZE            242

/*!
 * LoRaWAN ETSI duty cycle control enable/disable
 *
 * \remark Please note that ETSI mandates duty cycled transmissions. Use only for test purposes
 */
#define LORAWAN_DUTYCYCLE_ON                        true

/*!
 * LoRaWAN application port
 * @remark The allowed port range is from 1 up to 223. Other values are reserved.
 */
#define LORAWAN_APP_PORT                            2

NvProperty<uint8_t>  gActiveRegion(LORAMAC_REGION_EU868, LORAMAC_REGION_RU864, ACTIVE_REGION, NvVar::LORA_REGION);
NvProperty<uint32_t> gLoraAppTxDutyCycle(1000,  1000u * 60u * 60u * 24u* 31u, APP_TX_DUTYCYCLE, NvVar::LORA_TX_DUTYCYCLE);//2678400000
NvProperty<uint16_t> gLoraAppTxDutyCycleRnd(100,  1000 * 2, APP_TX_DUTYCYCLE_RND, NvVar::LORA_TX_DUTYCYCLE_RND);
NvProperty<uint8_t>  gLoraAdrState(0,  1, LORAWAN_ADR_STATE, NvVar::LORA_ADR_STATE);
NvProperty<uint8_t>  gLoraDefaultDatarate(DR_0,  DR_15, LORAWAN_DEFAULT_DATARATE, NvVar::LORA_DEFAULT_DATARATE);
NvProperty<uint8_t>  gLoraAppPort(1,  223, LORAWAN_APP_PORT, NvVar::LORA_APP_PORT);

/*!
 *
 */
typedef enum
{
    LORAMAC_HANDLER_TX_ON_TIMER,
    LORAMAC_HANDLER_TX_ON_EVENT,
}LmHandlerTxEvents_t;


/*!
 * User application data
 */
static uint8_t AppDataBuffer[LORAWAN_APP_DATA_BUFFER_MAX_SIZE];

/*!
 * User application data structure
 */
LmHandlerAppData_t AppData =
{

    .Port = 0,
	.BufferSize = 0,
	.Buffer = AppDataBuffer
};

/*!
 * Specifies the state of the application LED
 */
static bool AppLedStateOn = false;

/*!
 * Timer to handle the application data transmission duty cycle
 */
static osTimerId_t TxTimer;

osSemaphoreDef(UplinkSem);
osSemaphoreId gUplinkSem;

void StartTaskDefault(void * argument);
osThreadId defaultTaskHandle;
LoraNode* gLoraNode = nullptr;

static void OnMacProcessNotify( void );
static void OnNvmDataChange( LmHandlerNvmContextStates_t state, uint16_t size );
static void OnNetworkParametersChange( CommissioningParams_t* params );
static void OnMacMcpsRequest( LoRaMacStatus_t status, McpsReq_t *mcpsReq, TimerTime_t nextTxIn );
static void OnMacMlmeRequest( LoRaMacStatus_t status, MlmeReq_t *mlmeReq, TimerTime_t nextTxIn );
static void OnJoinRequest( LmHandlerJoinParams_t* params );
static void OnTxData( LmHandlerTxParams_t* params );
static void OnRxData( LmHandlerAppData_t* appData, LmHandlerRxParams_t* params );
static void OnClassChange( DeviceClass_t deviceClass );
static void OnBeaconStatusChange( LoRaMacHandlerBeaconParams_t* params );
#if( LMH_SYS_TIME_UPDATE_NEW_API == 1 )
static void OnSysTimeUpdate( bool isSynchronized, int32_t timeCorrection );
#else
static void OnSysTimeUpdate( void );
#endif
static void PrepareTxFrame( void );
static void StartTxProcess( LmHandlerTxEvents_t txEvent );
static void UplinkProcess( void );

static void OnTxPeriodicityChanged( uint32_t periodicity );
static void OnTxFrameCtrlChanged( LmHandlerMsgTypes_t isTxConfirmed );
static void OnPingSlotPeriodicityChanged( uint8_t pingSlotPeriodicity );

/*!
 * Function executed on TxTimer event
 */
static void OnTxTimerEvent( void* context );

/*!
 * Function executed on Led 1 Timeout event
 */
static void OnLed1TimerEvent(void* context );

/*!
 * \brief Function executed on Beacon timer Timeout event
 */
static void OnLedBeaconTimerEvent(void* context );

static LmHandlerCallbacks_t LmHandlerCallbacks =
{
    .GetBatteryLevel = BoardGetBatteryLevel,
    .GetTemperature = BoardGetTemperature,
    .GetRandomSeed = BoardGetRandomSeed,
    .OnMacProcess = OnMacProcessNotify,
    .OnNvmDataChange = OnNvmDataChange,
    .OnNetworkParametersChange = OnNetworkParametersChange,
    .OnMacMcpsRequest = OnMacMcpsRequest,
    .OnMacMlmeRequest = OnMacMlmeRequest,
    .OnJoinRequest = OnJoinRequest,
    .OnTxData = OnTxData,
    .OnRxData = OnRxData,
    .OnClassChange= OnClassChange,
    .OnBeaconStatusChange = OnBeaconStatusChange,
    .OnSysTimeUpdate = OnSysTimeUpdate,
};

static LmHandlerParams_t LmHandlerParams =  {
        .Region = (LoRaMacRegion_t)(uint8_t)gActiveRegion,
        .AdrEnable = (bool) gLoraAdrState,
        .IsTxConfirmed = LORAWAN_DEFAULT_CONFIRMED_MSG_STATE,
        .TxDatarate = (int8_t)gLoraDefaultDatarate,
        .PublicNetworkEnable = LORAWAN_PUBLIC_NETWORK,
        .DutyCycleEnabled = LORAWAN_DUTYCYCLE_ON,
        .DataBufferMaxSize = LORAWAN_APP_DATA_BUFFER_MAX_SIZE,
        .DataBuffer = AppDataBuffer,
        .PingSlotPeriodicity = REGION_COMMON_DEFAULT_PING_SLOT_PERIODICITY,
    };


static LmhpComplianceParams_t LmhpComplianceParams =
{
    .FwVersion = {.Value = FIRMWARE_VERSION},
    .OnTxPeriodicityChanged = OnTxPeriodicityChanged,
    .OnTxFrameCtrlChanged = OnTxFrameCtrlChanged,
    .OnPingSlotPeriodicityChanged = OnPingSlotPeriodicityChanged,
};

/*!
 * Indicates if LoRaMacProcess call is pending.
 * 
 * \warning If variable is equal to 0 then the MCU can be set in low power mode
 */
static volatile uint8_t IsMacProcessPending = 0;

static volatile uint32_t TxPeriodicity = 0;

/*!
 * LED GPIO pins objects
 */
extern Gpio_t Led1; // Tx

/*!
 * Timer to handle the state of LED1
 */
static osTimerId_t Led1Timer;
#define LED1_TIMER_TIMEOUT 25
/*!
 * Timer to handle the state of LED beacon indicator
 */
static osTimerId_t LedBeaconTimer;
#define LED_BEACON_TIMER_TIMEOUT 5000

static struct Leds{
	Gpio_t &pio;
	osTimerId_t &timer;
	uint16_t   timeout;
}gLeds[] = {{Led1, Led1Timer, LED1_TIMER_TIMEOUT}};

#define LED_SWITCH_ON(led) {DBG("LED:%i:%i\n", led, LED_OFF);GpioWrite( &gLeds[led].pio, LED_ON ); osTimerStart( gLeds[led].timer, gLeds[led].timeout );}
#define LED_SWITCH_OFF(led)    {DBG("LED:%i:%i\n", led, LED_OFF);osTimerStop( gLeds[led].timer ); GpioWrite( &gLeds[led].pio, LED_OFF );}

void UpdateHadlerProps(){

}
/* USER CODE BEGIN Header_StartTaskLeakMeter */
/**
* @brief Function implementing the leakMeterTask thread.
* @param argument: Not used
* @retval None
*/
/* USER CODE END Header_StartTaskLeakMeter */
void StartTaskDefault(void * argument)
{
  /* USER CODE BEGIN StartTaskLeakMeter */

	Led1Timer = osTimerNew( OnLed1TimerEvent, osTimerOnce, NULL, NULL );


	LedBeaconTimer = osTimerNew( OnLedBeaconTimerEvent, osTimerOnce, NULL, NULL );

    const Version_t appVersion = { .Value = FIRMWARE_VERSION };
    const Version_t gitHubVersion = { .Value = GITHUB_VERSION };
    DisplayAppInfo( "periodic-uplink-lpp",
                    &appVersion,
                    &gitHubVersion );
    BoardPrintUUID();
    BoardPrintSID();
    // Initialize transmission periodicity variable
    TxPeriodicity = gLoraAppTxDutyCycle + randr( -gLoraAppTxDutyCycleRnd, gLoraAppTxDutyCycleRnd );
    LmHandlerParams =   {
        .Region = (LoRaMacRegion_t)(uint8_t)gActiveRegion,
        .AdrEnable = (bool)gLoraAdrState,
        .IsTxConfirmed = LORAWAN_DEFAULT_CONFIRMED_MSG_STATE,
        .TxDatarate = (int8_t)gLoraDefaultDatarate,
        .PublicNetworkEnable = LORAWAN_PUBLIC_NETWORK,
        .DutyCycleEnabled = LORAWAN_DUTYCYCLE_ON,
        .DataBufferMaxSize = LORAWAN_APP_DATA_BUFFER_MAX_SIZE,
        .DataBuffer = AppDataBuffer,
        .PingSlotPeriodicity = REGION_COMMON_DEFAULT_PING_SLOT_PERIODICITY,
    };

    BoardInitPeriph(); // init lora hardware in the task context (drivers modified to use os timers)

    if ( LmHandlerInit( &LmHandlerCallbacks, &LmHandlerParams ) != LORAMAC_HANDLER_SUCCESS )
    {
        printf( "LoRaMac wasn't properly initialized\n" );
        Eeprom::erase();
        NvmDataMgmtFactoryReset( );
        BoardResetMcu();
    }

    // Set system maximum tolerated rx error in milliseconds
    LmHandlerSetSystemMaxRxError( 20 );

    // The LoRa-Alliance Compliance protocol package should always be
    // initialized and activated.
    LmHandlerPackageRegister( PACKAGE_ID_COMPLIANCE, &LmhpComplianceParams );

    LmHandlerJoin( );

    StartTxProcess( LORAMAC_HANDLER_TX_ON_TIMER );

  /* Infinite loop */
  for(;;)
  {

          // Process characters sent over the command line interface
          CliProcess( stdin );
          // Processes the LoRaMac events
          LmHandlerProcess( );
          // Process application uplinks management
          UplinkProcess( );

          CRITICAL_SECTION_BEGIN( );
          if( IsMacProcessPending == 1 )
          {
              // Clear flag and prevent MCU to go into low power modes.
              IsMacProcessPending = 0;
          }
          else
          {
              // The MCU wakes up through events
//#ifndef DEBUG
      //        BoardLowPowerHandler( );
//#endif
          }
          CRITICAL_SECTION_END( );
  }
  /* USER CODE END StartTaskLeakMeter */
}


const osThreadAttr_t thread_attr = {
  .name = "default",
  .stack_size = 512 * 4                            // Create the thread stack with a size of 1024 bytes
};
/*!
 * Main application entry point.
 */
int main(void){
	//Not needed but for compatibility
    BoardInitMcu( );
    osKernelInitialize();   // pre initialize CMSIS-RTOS

    MessageBus& mbus = InitOneWire();
    InitModBus(mbus);
    gLoraNode = &InitLoraNode(mbus);
    defaultTaskHandle = osThreadNew(StartTaskDefault, &mbus, &thread_attr);
    assert(defaultTaskHandle);

    // create semaphores
    gUplinkSem = osSemaphoreNew(1, 0, nullptr);
    assert(gUplinkSem);

	DBG("Heap %i\n", xPortGetFreeHeapSize());
	if (osKernelGetState() == osKernelReady) {
		osKernelStart();
	}
	while(1) {
		assert(0);
	}
}

static void OnMacProcessNotify( void )
{
    IsMacProcessPending = 1;
}

static void OnNvmDataChange( LmHandlerNvmContextStates_t state, uint16_t size )
{
    DisplayNvmDataChange( state, size );
}

static void OnNetworkParametersChange( CommissioningParams_t* params )
{
    DisplayNetworkParametersUpdate( params );
}

static void OnMacMcpsRequest( LoRaMacStatus_t status, McpsReq_t *mcpsReq, TimerTime_t nextTxIn )
{
    DisplayMacMcpsRequestUpdate( status, mcpsReq, nextTxIn );
}

static void OnMacMlmeRequest( LoRaMacStatus_t status, MlmeReq_t *mlmeReq, TimerTime_t nextTxIn )
{
    DisplayMacMlmeRequestUpdate( status, mlmeReq, nextTxIn );
}

static void OnJoinRequest( LmHandlerJoinParams_t* params )
{
    DisplayJoinRequestUpdate( params );
    if( params->Status == LORAMAC_HANDLER_ERROR )
    {
        LmHandlerJoin( );
    }
    else
    {
        LmHandlerRequestClass( LORAWAN_DEFAULT_CLASS );
    }
}

static void OnTxData( LmHandlerTxParams_t* params )
{
    DisplayTxUpdate( params );
}

static void OnRxData( LmHandlerAppData_t* appData, LmHandlerRxParams_t* params )
{
    DisplayRxUpdate( appData, params );
//TODO:rx data process
    switch( appData->Port )
    {
    case 1: // The application LED can be controlled on port 1 or 2
    case LORAWAN_APP_PORT:
        {
            AppLedStateOn = appData->Buffer[0] & 0x01;
        }
        break;
    default:
        break;
    }

    // Switch LED 2 ON for each received downlink
    LED_SWITCH_ON(LedsType::LED1);
}

static void OnClassChange( DeviceClass_t deviceClass )
{
    DisplayClassUpdate( deviceClass );

    // Inform the server as soon as possible that the end-device has switched to ClassB
    LmHandlerAppData_t appData =
    {
        .Port = 0,
		.BufferSize = 0,
		.Buffer = NULL,
    };
    LmHandlerSend( &appData, LORAMAC_HANDLER_UNCONFIRMED_MSG );
}

static void OnBeaconStatusChange( LoRaMacHandlerBeaconParams_t* params )
{
    switch( params->State )
    {
        case LORAMAC_HANDLER_BEACON_RX:
        {
            osTimerStart( LedBeaconTimer, LED_BEACON_TIMER_TIMEOUT );
            break;
        }
        case LORAMAC_HANDLER_BEACON_LOST:
        case LORAMAC_HANDLER_BEACON_NRX:
        {
            osTimerStop( LedBeaconTimer );
            break;
        }
        default:
        {
            break;
        }
    }

    DisplayBeaconUpdate( params );
}

#if( LMH_SYS_TIME_UPDATE_NEW_API == 1 )
static void OnSysTimeUpdate( bool isSynchronized, int32_t timeCorrection )
{

}
#else
static void OnSysTimeUpdate( void )
{

}
#endif

/*!
 * Prepares the payload of the frame and transmits it.
 */
static void PrepareTxFrame( void )
{
	static bool NewDataAvailable = false;
    if( LmHandlerIsBusy( ) == true )
    {
    	DBG("busy\n");
        return;
    }

    AppData.Port = LORAWAN_APP_PORT;

    NewDataAvailable =!NewDataAvailable? osSemaphoreAcquire(gLoraNode->AppDataChanged(), 10) == osOK : NewDataAvailable;

    {
    	NewDataAvailable = false;
    	gLoraNode->DataSend();
    	 DBG("DATA SENT\n");
        // Switch LED 1 ON
    	LED_SWITCH_ON(LedsType::LED1);
    }
}

static void StartTxProcess( LmHandlerTxEvents_t txEvent )
{
    switch( txEvent )
    {
    default:
        // Intentional fall through
    case LORAMAC_HANDLER_TX_ON_TIMER:
        {
            // Schedule 1st packet transmission
           TxTimer = osTimerNew( OnTxTimerEvent, osTimerOnce, NULL, NULL  );
           osTimerStart(TxTimer, TxPeriodicity);
           OnTxTimerEvent( NULL );
        }
        break;
    case LORAMAC_HANDLER_TX_ON_EVENT:
        {
        }
        break;
    }
}

static void UplinkProcess( void )
{
    if(osSemaphoreAcquire(gUplinkSem, 50) == osOK)
    {
        PrepareTxFrame( );
    }
}

static void OnTxPeriodicityChanged( uint32_t periodicity )
{
    TxPeriodicity = periodicity;

    if( TxPeriodicity == 0 )
    { // Revert to application default periodicity
       TxPeriodicity = gLoraAppTxDutyCycle + randr( -gLoraAppTxDutyCycleRnd, gLoraAppTxDutyCycleRnd );
    }
    DBG("%s\n", __FUNCTION__);
    // Update timer periodicity
    osTimerStop(TxTimer );
    osTimerStart(TxTimer, TxPeriodicity);
}

static void OnTxFrameCtrlChanged( LmHandlerMsgTypes_t isTxConfirmed )
{
	DBG("%s\n", __FUNCTION__);
    LmHandlerParams.IsTxConfirmed = isTxConfirmed;
}

static void OnPingSlotPeriodicityChanged( uint8_t pingSlotPeriodicity )
{
    LmHandlerParams.PingSlotPeriodicity = pingSlotPeriodicity;
}

/*!
 * Function executed on TxTimer event
 */
static void OnTxTimerEvent( void* context )
{
    osTimerStop(TxTimer );

    osSemaphoreRelease(gUplinkSem);//release semaphore as they created as available

    // Schedule next transmission
    osTimerStart( TxTimer, TxPeriodicity);
}

/*!
 * Function executed on Led 1 Timeout event
 */
static void OnLed1TimerEvent(void* context )
{
	// Switch LED 1 OFF
    LED_SWITCH_OFF(LedsType::LED1);
}

/*!
 * \brief Function executed on Beacon timer Timeout event
 */
static void OnLedBeaconTimerEvent(void* context )
{
	// Switch LED 2 ON
    LED_SWITCH_ON(LedsType::LED1);
    osTimerStart( LedBeaconTimer, LED_BEACON_TIMER_TIMEOUT );
}

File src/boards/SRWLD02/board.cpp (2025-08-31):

/*!
 * \file      board.c
 *
 * \brief     Target board general functions implementation
 *
 * \copyright Revised BSD License, see section \ref LICENSE.
 *
 * \code
 *                ______                              _
 *               / _____)             _              | |
 *              ( (____  _____ ____ _| |_ _____  ____| |__
 *               \____ \| ___ |    (_   _) ___ |/ ___)  _ \
 *               _____) ) ____| | | || |_| ____( (___| | | |
 *              (______/|_____)_|_|_| \__)_____)\____)_| |_|
 *              (C)2013-2017 Semtech
 *
 * \endcode
 *
 * \author    Miguel Luis ( Semtech )
 *
 * \author    Gregory Cristian ( Semtech )
 */
#include <cassert>
#include <cstring>
#include <string.h>
#include <math.h>
#include <time.h>
#include "stm32wlxx.h"
#include "utilities.h"
#include "gpio.h"
#include "adc.h"
#include "spi.h"
#include "i2c.h"
#include "uart.h"
#include "timer.h"
#include "sysIrqHandlers.h"
#include "board-config.h"
#include "lpm-board.h"
#include "rtc-board.h"
#include "cmsis_os.h"
#include "OneWire.h"
#include "Ds18B20.h"
#include "FreeRTOS.h"
#include "sensors-board.h"
#include "bq35100.h"
#include "stm32wlxx_board_radio.h"
#include "timemacro.h"
#include "board.h"
#include "nonvol.h"

/*!
 * Unique Devices IDs register set ( STM32WL5x )
 */
#define U_ID          0x1FFF7590

/*!
 * Unique Devices IDs register set ( STM32F103xE )
 */
#pragma pack(push, 1)
union Usid {
	struct{
		union {
			struct{
				uint16_t x;
				uint16_t y;
			};
			uint32_t xy;
		}pos;
		uint8_t  wafer;
		char     lot[7];
	};
	uint8_t bytes[12];
} *UniqueSiliconID = (union Usid *)U_ID;
#pragma pack(pop)



#define ID1 ((uint32_t*)(U_ID + 0x0))
#define ID2 ((uint32_t*)(U_ID + 0x4))
#define ID3 ((uint32_t*)(U_ID + 0x14))


#define ARRAY_SIZE(x) (sizeof(x)/sizeof(x[0]))
#define INITIAL_BATTERY_DATE UNIX_TIMESTAMP(2025, 5, 10, 9, 26, 13)
#define MAX_BATTERY_DATE UNIX_TIMESTAMP(2055, 5, 10, 9, 26, 13)
#define INITIAL_BATTERY_CAPACITY 6500
/*!
 * LED GPIO pins objects
 */
Gpio_t Led1;
Gpio_t PowerOffAndWakeup = {.pin = POWER_OFF_AND_WAKEUP};
Gpio_t BattPwr;
Gpio_t SensorsEn[MUX_COUNT]= {{.pin = EN0}, {.pin = EN1}};
Gpio_t SensorsPolarity = {.pin = SENS_PSEL};

/*
 * MCU objects
 */
Adc_t  AdcVref = {.inst = ADC, .channel = ADC_CHANNEL_VREFINT };
Adc_t  AdcTempSens = {.inst = ADC, .channel = ADC_CHANNEL_TEMPSENSOR};
Adc_t  AdcInP = {.inst = ADC, .channel = ADC_CH_P};
Adc_t  AdcVbat = {.inst = ADC, .channel = ADC_CHANNEL_VBAT};

Uart_t LpUart1;
Uart_t Usart1;

I2C  i2c1(I2C_1, I2C1_SCL, I2C1_SDA);
BatteryGaugeBq35100 gauge(&i2c1);

IWDG_HandleTypeDef hiwdg;
PKA_HandleTypeDef hpka;
RNG_HandleTypeDef hrng;

OneWire::Bus gOWI(&LpUart1);
OneWire::DS18B20 gDs18b20(&gOWI, OneWire::DS18B20::Resolution::SR12BITS);

NvProperty<uint32_t>  gBatteryReplacementDate(INITIAL_BATTERY_DATE,  MAX_BATTERY_DATE , INITIAL_BATTERY_DATE, NvVar::BATT_INS_DATE);

int bcd2int(uint16_t bcd_value) {
    int result = 0;
    int multiplier = 1;

    // Process each 4-bit nibble from right to left (least significant to most significant)
    while (bcd_value > 0) {
        // Extract the rightmost BCD digit (4 bits)
        int digit = bcd_value & 0xF;

        // Check if the extracted digit is a valid BCD digit (0-9)
        if (digit > 9) {
            // Handle invalid BCD digit (e.g., return an error or specific value)
            // For simplicity, this example assumes valid BCD.
            return -1; // Indicate an error
        }

        // Add the decimal value of the digit to the result, scaled by its place value
        result += digit * multiplier;

        // Shift the BCD value to the right by 4 bits to process the next digit
        bcd_value >>= 4;

        // Increase the multiplier for the next digit's place value (tens, hundreds, etc.)
        multiplier *= 10;
    }

    return result;
}

/*!
 * Initializes the unused GPIO to a know status
 */
static void BoardUnusedIoInit( void );

/*!
 * System Clock Configuration
 */
static void SystemClockConfig( void );

/*!
 * System Clock Re-Configuration when waking up from STOP mode
 */
static void SystemClockReConfig( void );

extern "C" void initialise_monitor_handles(void);

void configureTimerForRunTimeStats(void);
unsigned long getRunTimeCounterValue(void);
void Error_Handler(void);
/*!
 * Flag to indicate if the MCU is Initialized
 */
static bool McuInitialized = false;

/*!
 * UART2 FIFO buffers size
 */
#define LPUART1_FIFO_TX_SIZE                                128
#define LPUART1_FIFO_RX_SIZE                                128

#define USART1_FIFO_TX_SIZE                                128
#define USART1_FIFO_RX_SIZE                                128

uint8_t LpUart1TxBuffer[LPUART1_FIFO_TX_SIZE];
uint8_t LpUart1RxBuffer[LPUART1_FIFO_RX_SIZE];

uint8_t Usart1TxBuffer[USART1_FIFO_TX_SIZE];
uint8_t Usart1RxBuffer[USART1_FIFO_RX_SIZE];

void BoardCriticalSectionBegin( UBaseType_t *mask )
{
    *mask = taskENTER_CRITICAL_FROM_ISR();
}
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

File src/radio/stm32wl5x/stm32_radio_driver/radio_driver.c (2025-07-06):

/*!
 * \file      radio_driver.c
 *
 * \brief     radio driver implementation
 *
 * \copyright Revised BSD License, see section \ref LICENSE.
 *
 * \code
 *                ______                              _
 *               / _____)             _              | |
 *              ( (____  _____ ____ _| |_ _____  ____| |__
 *               \____ \| ___ |    (_   _) ___ |/ ___)  _ \
 *               _____) ) ____| | | || |_| ____( (___| | | |
 *              (______/|_____)_|_|_| \__)_____)\____)_| |_|
 *              (C)2013-2017 Semtech
 *
 * \endcode
 *
 * \author    Miguel Luis ( Semtech )
 *
 * \author    Gregory Cristian ( Semtech )
 */
/**
  ******************************************************************************
  *
  *          Portions COPYRIGHT 2020 STMicroelectronics
  *
  * @file    radio_driver.c
  * @author  MCD Application Team
  * @brief   radio driver implementation
  ******************************************************************************
  */
/* Includes ------------------------------------------------------------------*/
#include "radio_driver.h"
#include "mw_log_conf.h"
#include "stm32wlxx.h"
/* External variables ---------------------------------------------------------*/
/*!
 * \brief Sughz handler
 */
extern SUBGHZ_HandleTypeDef hsubghz;

/* Private typedef -----------------------------------------------------------*/
/*!
 * FSK bandwidth definition
 */
typedef struct FskBandwidth_s
{
    uint32_t bandwidth;
    uint8_t  RegValue;
} FskBandwidth_t;
/* Private define ------------------------------------------------------------*/
/**
  * @brief drive value used anytime radio is NOT in TX low power mode
  * @note SMPS_DRIVE_SETTING_DEFAULT can be redefined in radio_conf.h
  */
#ifndef SMPS_DRIVE_SETTING_DEFAULT
#define SMPS_DRIVE_SETTING_DEFAULT  SMPS_DRV_40
#endif /* SMPS_DRIVE_SETTING_DEFAULT */

/**
  * @brief drive value used anytime radio is in TX low power mode
  *        TX low power mode is the worst case because the PA sinks from SMPS
  *        while in high power mode, current is sunk directly from the battery
  * @note SMPS_DRIVE_SETTING_MAX can be redefined in radio_conf.h
  */
#ifndef SMPS_DRIVE_SETTING_MAX
#define SMPS_DRIVE_SETTING_MAX      SMPS_DRV_60
#endif /* SMPS_DRIVE_SETTING_MAX */

/**
  * @brief Provides the frequency of the chip running on the radio and the frequency step
  * @remark These defines are used for computing the frequency divider to set the RF frequency
  * @note XTAL_FREQ can be redefined in radio_conf.h
  */
#ifndef XTAL_FREQ
#define XTAL_FREQ                   ( 32000000UL )
#endif /* XTAL_FREQ */

/**
  * @brief in XO mode, set internal capacitor (from 0x00 to 0x2F starting 11.2pF with 0.47pF steps)
  * @note XTAL_DEFAULT_CAP_VALUE can be redefined in radio_conf.h
  */
#ifndef XTAL_DEFAULT_CAP_VALUE
#define XTAL_DEFAULT_CAP_VALUE      ( 0x20UL )
#endif /* XTAL_DEFAULT_CAP_VALUE */

/**
  * @brief voltage of vdd tcxo.
  * @note TCXO_CTRL_VOLTAGE can be redefined in radio_conf.h
  */
#ifndef TCXO_CTRL_VOLTAGE
#define TCXO_CTRL_VOLTAGE           TCXO_CTRL_1_7V
#endif /* TCXO_CTRL_VOLTAGE */

/**
  * @brief Radio maximum wakeup time (in ms)
  * @note RF_WAKEUP_TIME can be redefined in radio_conf.h
  */
#ifndef RF_WAKEUP_TIME
#define RF_WAKEUP_TIME              ( 10UL )
#endif /* RF_WAKEUP_TIME */

/**
  * @brief DCDC is present and enabled
  * @remark this define is only used if the DCDC is present on the board
  * @note DCDC_ENABLE can be redefined in radio_conf.h
  */
#ifndef DCDC_ENABLE
#define DCDC_ENABLE                 ( 1UL )
#endif /* DCDC_ENABLE */

/* Private macro -------------------------------------------------------------*/
/* Private variables ---------------------------------------------------------*/
/*!
 * \brief Holds the internal operating mode of the radio
 */
static RadioOperatingModes_t OperatingMode;

/*!
 * \brief Stores the current packet type set in the radio
 */
static RadioPacketTypes_t PacketType;

/*!
 * \brief Stores the current packet header type set in the radio
 */
static volatile RadioLoRaPacketLengthsMode_t LoRaHeaderType;

/*!
 * \brief Stores the last frequency error measured on LoRa received packet
 */
volatile uint32_t FrequencyError = 0;

/*!
 * \brief Hold the status of the Image calibration
 */
static bool ImageCalibrated = false;

/*!
 * Precomputed FSK bandwidth registers values
 */
static const FskBandwidth_t FskBandwidths[] =
{
    { 4800  , 0x1F },
    { 5800  , 0x17 },
    { 7300  , 0x0F },
    { 9700  , 0x1E },
    { 11700 , 0x16 },
    { 14600 , 0x0E },
    { 19500 , 0x1D },
    { 23400 , 0x15 },
    { 29300 , 0x0D },
    { 39000 , 0x1C },
    { 46900 , 0x14 },
    { 58600 , 0x0C },
    { 78200 , 0x1B },
    { 93800 , 0x13 },
    { 117300, 0x0B },
    { 156200, 0x1A },
    { 187200, 0x12 },
    { 234300, 0x0A },
    { 312000, 0x19 },
    { 373600, 0x11 },
    { 467000, 0x09 },
    { 500000, 0x00 }, // Invalid Bandwidth
};

/* Private function prototypes -----------------------------------------------*/

/*!
 * \brief This set SMPS drive capability wrt. RF mode
 *
 * \param [in]  level       SMPS maximum drive capability level
 */
static void Radio_SMPS_Set( uint8_t level );

/*!
 * \brief IRQ Callback radio function
 */
static DioIrqHandler RadioOnDioIrqCb;

/* Exported functions ---------------------------------------------------------*/
void SUBGRF_Init( DioIrqHandler dioIrq )
{
    if ( dioIrq != NULL)
    {
        RadioOnDioIrqCb = dioIrq;
    }

    RADIO_INIT();

    /* set default SMPS current drive to default*/
    Radio_SMPS_Set(SMPS_DRIVE_SETTING_DEFAULT);

    ImageCalibrated = false;

    SUBGRF_SetStandby( STDBY_RC );

    // Initialize TCXO control
    if (1U == RBI_IsTCXO() )
    {
        SUBGRF_SetTcxoMode( TCXO_CTRL_VOLTAGE, RF_WAKEUP_TIME << 6 );// 100 ms
        SUBGRF_WriteRegister( REG_XTA_TRIM, 0x00 );

        /*enable calibration for cut1.1 and later*/
        CalibrationParams_t calibParam;
        calibParam.Value = 0x7F;
        SUBGRF_Calibrate( calibParam );
    }
    else
    {
        SUBGRF_WriteRegister( REG_XTA_TRIM, XTAL_DEFAULT_CAP_VALUE );
        SUBGRF_WriteRegister( REG_XTB_TRIM, XTAL_DEFAULT_CAP_VALUE );
    }

    /* WORKAROUND - Trimming the output voltage power_ldo to 3.3V */
    SUBGRF_WriteRegister(REG_DRV_CTRL, 0x7 << 1);

    /* Init RF Switch */
    RBI_Init();

    OperatingMode = MODE_STDBY_RC;
}

RadioOperatingModes_t SUBGRF_GetOperatingMode( void )
{
    return OperatingMode;
}

void SUBGRF_SetPayload( uint8_t *payload, uint8_t size )
{
    SUBGRF_WriteBuffer( 0x00, payload, size );
}

uint8_t SUBGRF_GetPayload( uint8_t *buffer, uint8_t *size,  uint8_t maxSize )
{
    uint8_t offset = 0;

    SUBGRF_GetRxBufferStatus( size, &offset );
    if( *size > maxSize )
    {
        return 1;
    }
    SUBGRF_ReadBuffer( offset, buffer, *size );

    return 0;
}
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

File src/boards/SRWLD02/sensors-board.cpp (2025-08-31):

/*
 * sensors.cpp
 *
 *  Created on: Jan 18, 2025
 *      Author: Andrey
 */



#include <cassert>
#include <cfloat>
#include <climits>
#include <cmath>
#include <cmsis_os.h>

#include "stm32wlxx.h"
#include "utilities.h"
#include "gpio.h"
#include "sensors-board.h"
#include "stm32wlxx_ll_adc.h"
#include "board-config.h"
#include "adc.h"
#include "fsmlist.h"
#include "board.h"

#define DEBUG

#define DEBUG_SAMPLING 0

#define VDDA_MIN 2600
#define VDDA_MAX 3610

#define CHANNELS_PER_MUX_BLOCK 10
#define CALIBRATION_AVERAGE 20
#define SAMPLING_AVERAGE 2
#define MUX_BLOCKS 2
#define REFERENCE_RES_HI 100000.0
#define REFERENCE_RES_LO 1000.0
#define REFERENCE_RES_TOLERANCE 1.0
#define MAX_ERROR 5
#define MAX_SHIFT_ERROR 1000

#define DEFAULT_SAMPLE_PERIOD 1000 //ms

float calc_temperature(uint16_t __VREFANALOG_VOLTAGE__,int16_t  __TEMPSENSOR_ADC_DATA__, uint8_t __ADC_RESOLUTION__){

	/*
	 *  Temperature = ((TS_ADC_DATA - TS_CAL1) * (TS_CAL2_TEMP - TS_CAL1_TEMP)) / (TS_CAL2 - TS_CAL1) + TS_CAL1_TEMP
	 */
    float TS_CAL1 = FB2B((int32_t) *TEMPSENSOR_CAL1_ADDR, 12, __ADC_RESOLUTION__);
	float TS_CAL2 = FB2B((int32_t) *TEMPSENSOR_CAL2_ADDR, 12, __ADC_RESOLUTION__);
	float TEMPSENSOR_CAL_TEMP_DIFF = (TEMPSENSOR_CAL2_TEMP - TEMPSENSOR_CAL1_TEMP);
	float TEMPSENSOR_CAL_DIFF = (TS_CAL2 - TS_CAL1);
	float TS_ADC_DATA = (__TEMPSENSOR_ADC_DATA__ * __VREFANALOG_VOLTAGE__) / TEMPSENSOR_CAL_VREFANALOG;
	if(TS_CAL2 - TS_CAL1)
		return ((TEMPSENSOR_CAL_TEMP_DIFF * (TS_ADC_DATA - TS_CAL1)) / TEMPSENSOR_CAL_DIFF) + TEMPSENSOR_CAL1_TEMP;
	else
		return	((int32_t)LL_ADC_TEMPERATURE_CALC_ERROR);
}

//4 ref c channel (2 on each half) + ts and vref
const ChannelConfig gChannelConfig[WL_CHANNEL_COUNT + CAL_CHANNEL_COUNT + VREF_VBAT_AND_TEMP_CHANNEL_COUNT] = {
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

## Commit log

2024-12-26 Rework one wire to cpp code
    [board-config.h, board.cpp, gpio-board.c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]
2024-12-27 Add temperature and relative humidity data gather and packing for the lora
2025-01-03 Add nonvolatile vars and rework modbus registers
    [board-config.h, board.cpp, main.cpp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]
2025-01-20 Revert usage of ds18b20 as internal temperature sensor and add ext/batt power selector as pf3
    [board-config.h, board.cpp, main.cpp]
2025-01-20 Fix tz on get time
    [rtc-board.c]
2025-01-22 Add adc calibration on setup
2025-01-22 Movefreertos sysview monitor counter to its place and fix voltage and temperature measurements
    [board.cpp]
2025-01-22 Fix baud rate calc on apply and add apply on changes of baud rate and another uart options
    [modbus.cpp]
2025-01-23 Fix spi init as slave
    [board.cpp, spi-board.c]
2025-01-23 Fix lora reset pin initialization
    [sx1276mb1las-board.c]
2025-01-23 Add delay differentiation as some code uses delay in interrupts
2025-01-23 Revert interrupt stack back to 0x400 bytes
2025-02-01 Add recursive mutex support and increase timer stack to 512 bytes
2025-02-01 Resstore spi implementation
2025-02-01 Add led def for led3 enum and led state
2025-02-01 Add adc deinit
2025-02-01 Update uart rtos integration and modbus
2025-02-01 move lora driver to os timers
2025-02-03 Add debug print of radio payload
2025-02-05 Add print of uid and silicon info and move some global variables to modbus source file
2025-02-17 Update cmsis to v2 and add dsp library, Move modbus lora and onewire task code to message bus nodes. fix modbus register access error
    [adc-board.c, board-config.h, board.cpp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]
2025-02-17 Add reg name to debug print
2025-02-24 Add ability to get current alarm counter value
2025-02-24 Remove unavailable pin names from config
2025-02-24 Add pre slee and post sleep methods for the board to utilize this abilities of rtos
2025-02-24 Comment manual low power processing. Change timer types to cmsis v2 only (this disables backward compatibility). Use rtos transmission timer Add led debug
2025-02-24 Add board shematic to the project
    [current-source.SchDoc, modbus-rtu.SchDoc, power.SchDoc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]
2025-02-25 Update schematic
    [current-source.SchDoc, jtag.SchDoc, modbus-rtu.SchDoc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]
2025-02-26 Replace xtal by txco, add antenna with matching, add swd for debug, fix some errors
    [modbus-rtu.SchDoc, power.SchDoc, sensors.SchDoc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]
2025-02-26 Add OneWire sheet
    [owi.SchDoc, stm32wl-cpu.SchDoc]
2025-02-26 Minor changes
    [owi.SchDoc, stm32wl-cpu.SchDoc, water-leak.PrjPcb]
2025-02-26 Add i2c pullup
    [stm32wl-cpu.SchDoc]
2025-02-27 Fix Errors
    [4 layers.PcbDoc, 4 layers.PrjPCB, current-source.SchDoc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]
2025-03-03 Begining of pcb routing
    [MB1720.PcbLib, current-source.SchDoc, sensor-conn.SchDoc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]
2025-03-04 Add Rooms/Net Classes and Initial placement
    [current-source.SchDoc, power.SchDoc, sensor-conn.SchDoc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]
2025-03-09 Partial placement, board edited to 80mm width
    [jtag.SchDoc, owi.SchDoc, power.SchDoc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]
2025-03-10 Modbus placement & planes
    [modbus-rtu.SchDoc, sensor-conn.SchDoc, sensors.SchDoc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]
2025-03-11 Change power ic and rf switch
    [power.SchDoc, stm32wl-mcu.SchDoc]
2025-03-11 Trim board to 120x80mm
2025-03-13 Update placement & add step model
    [4 layers.PcbDoc, sensors.SchDoc, stm32wl-mcu.SchDoc]
2025-03-13 Update sensors - just save
    [sensors.SchDoc]
2025-04-01 Shematic and board
    [4 layers.PcbDoc, current-source.SchDoc, d2se.SchDoc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]
2025-04-07 Fix mistype on variable name and change reported value to persent of adc ref voltage
    [4 layers.PcbDoc]
2025-04-18 Partial fix for backup temperature channel and current board state
    [4 layers.PcbDoc, stm32wl-mcu.SchDoc]
2025-04-21 Add OW bus dynamic power delivery
2025-04-23 Add gerber generation job
    [water-leak.PrjPcb]
2025-04-27 Test rev1
    [4 layers.GBL, 4 layers.GBO, 4 layers.GBP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]
2025-06-29 Current state
    [4 layers.PcbDoc, Bill of Materials-water-leak.xlsx, d2se.SchDoc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]
2025-07-06 Removes excessive protection
    [4 layers.PcbDoc, modbus-rtu.SchDoc]
2025-07-14 Initial build of srwld02 board code
2025-07-21 Remove one folder on path, Add sampler fsm, Add fota project as boot template for board 02, Remove usage of vrefbuf as unavailable in our package. Change eeprom code for board 02, Change hal timer to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
    [4 layers.PcbDoc, modbus-rtu.SchDoc]
2025-08-04 Fix for some errors. Adds battery gauge usage
    [board-config.h, board.cpp, i2c-board.c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]
2025-08-22 Oversampled sensors measurement works
    [4 layers.PcbDoc, jtag.SchDoc, owi.SchDoc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]
2025-08-31 Revision 2
    [4 layers.PcbDoc, d2se.SchDoc, jtag.SchDoc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]
2025-08-31 rev2 board
2025-08-31 Rev2 board files
    [4 layers.GBL, 4 layers.GBO, 4 layers.GBP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]
2025-09-01 Rev2 board files update
    [4 layers.GBL, 4 layers.GBO, 4 layers.GBP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]
2025-09-01 Rev2 board files update2
    [4 layers.GBL, 4 layers.GBO, 4 layers.GBP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]
